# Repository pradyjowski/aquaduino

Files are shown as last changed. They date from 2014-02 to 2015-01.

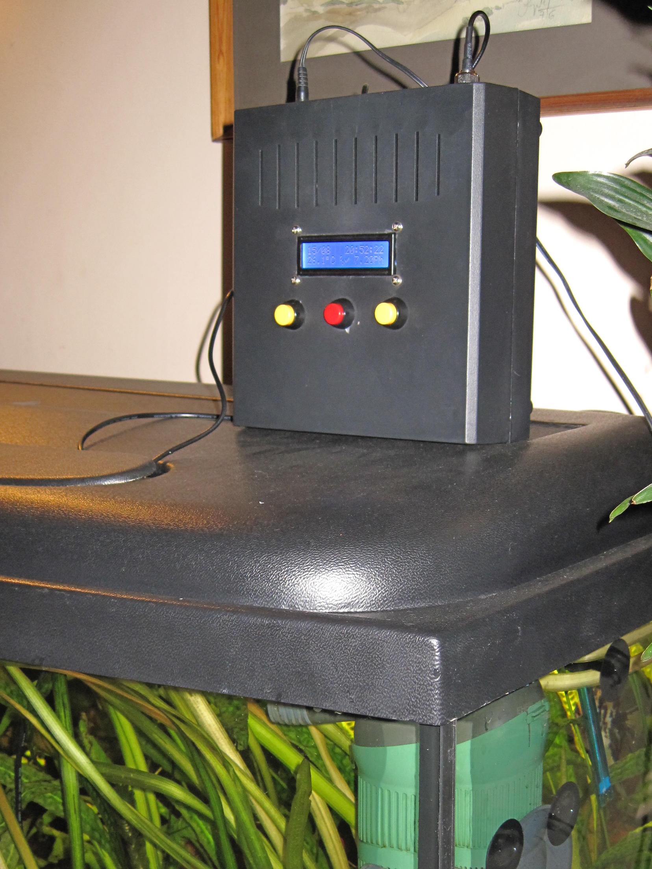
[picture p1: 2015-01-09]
IMG_3392.JPG

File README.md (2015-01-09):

aquaduino
=========

Arduino based aquarium controller measuring Ph and temperature, LCD-UI + RTC + datalogging SD

Achieved:
- LCD display over i2c interface
- Functional 3-button menu in English and Polish
- Ph probe reading with calibration code
- EEPROM save of Ph calibration
- Temperature reading [DS18B20]
- Data and clock [DS1307]
- SD card logging

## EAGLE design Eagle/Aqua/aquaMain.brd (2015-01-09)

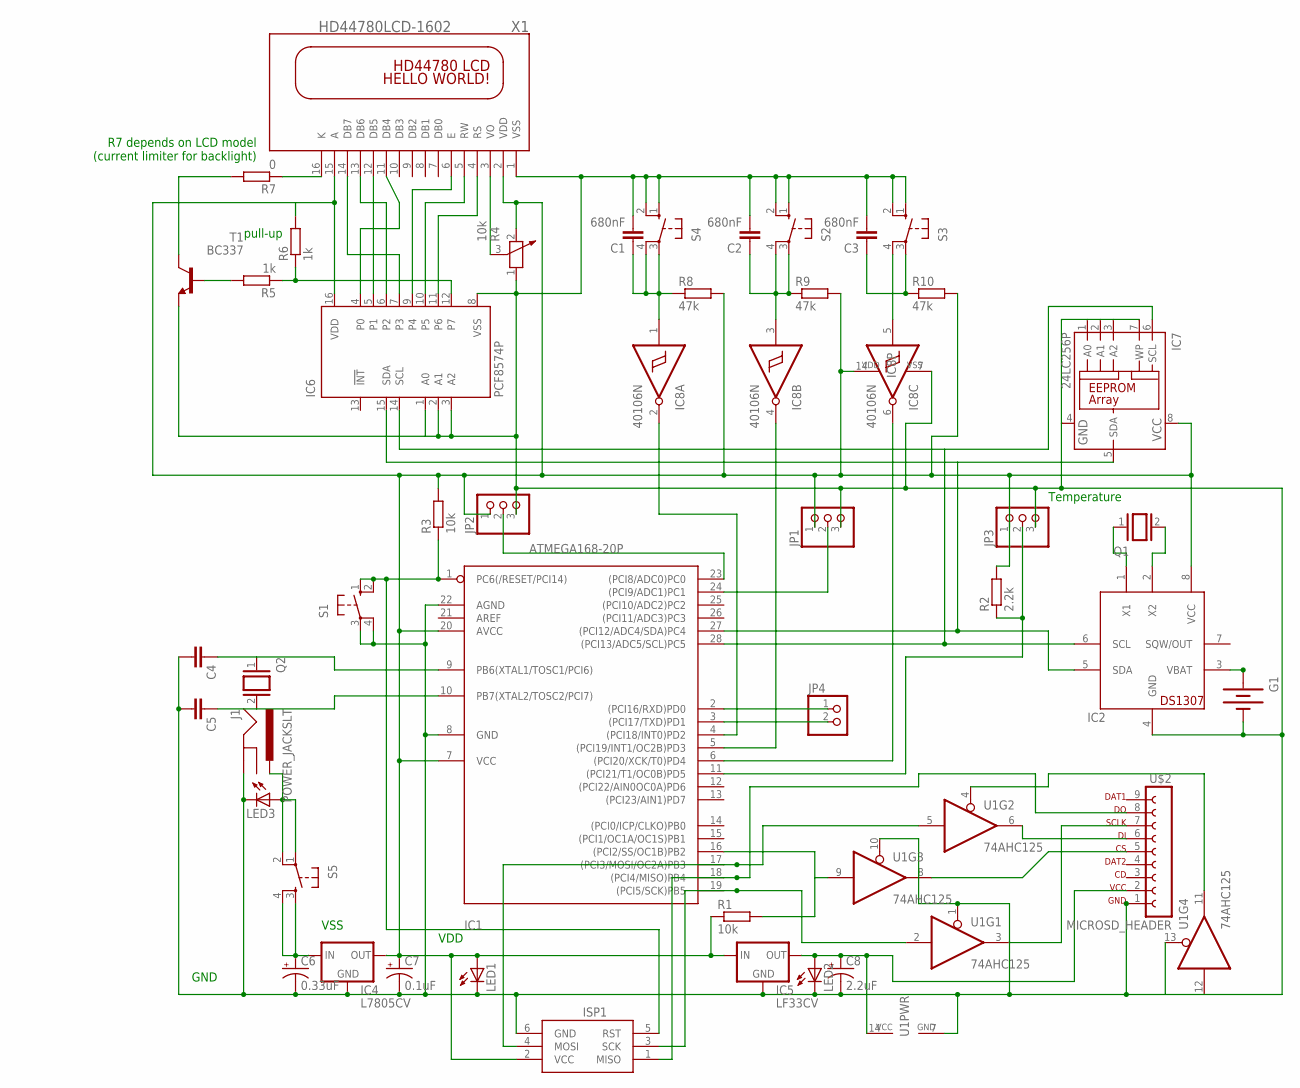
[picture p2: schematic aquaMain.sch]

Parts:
C1, C2, C3: 680nF; C050-050X075
C4, C5: C-EU025-024X044; C025-024X044
C6: 0.33uF; E5-6
C7: 0.1uF; E5-6
C8: 2.2uF; E5-6
G1: BATTERY20PTH; BATTCOM_20MM_PTH
IC1: ATMEGA168-20P; DIL28-3
IC2: DS1307; DIL08
IC4: L7805CV; TO220
IC5: LF33CV; TO220
IC6: PCF8574P; DIL16
IC7: 24LC256P; DIL8
IC8: 40106N; DIL14
ISP1: AVRISP-6; AVRISP
J1: POWER_JACKSLT; POWER_JACK_SLOT
JP1, JP2, JP3: PINHD-1X3; 1X03
JP4: PINHD-1X2; 1X02
LED1, LED2, LED3: LED3MM
Q1, Q2: XTAL/S; QS
R1, R3: 10k; 0204/7
R2: 2.2k; 0204/7
R4: 10k; PT-10
R5, R6: 1k; 0204/5
R7: 0; 0204/5
R8, R9, R10: 47k; 0204/5
S1, S2, S3, S4: 40-XX-ROUND; B3F-40XX-ROUND
S5: TAC_SWITCHPTH; TACTILE-PTH
T1: BC337; TO92
U1: 74AHC125; DIP14
U$2: MICROSD_HEADER; 9PINH
X1: HD44780LCD-1602; LCD1602

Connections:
unnamed: IC1.23 ((PCI8/ADC0)PC0), JP2.2
unnamed: IC1.5 ((PCI19/INT1/OC2B)PD3), IC8.4 (O)
unnamed: IC2.1 (X1), Q1.1
unnamed: IC2.2 (X2), Q1.2
unnamed: G1.1 (+), IC2.3 (VBAT)
unnamed: IC1.11 ((PCI21/T1/OC0B)PD5), JP3.2, R2.1
unnamed: IC1.28 ((PCI13/ADC5/SCL)PC5), IC2.6 (SCL), IC6.14 (SCL), IC7.6 (SCL)
unnamed: IC1.4 ((PCI18/INT0)PD2), IC8.2 (O)
unnamed: IC1.6 ((PCI20/XCK/T0)PD4), IC8.6 (O)
unnamed: C4.1, IC1.9 (PB6(XTAL1/TOSC1/PCI6)), Q2.1
unnamed: C5.1, IC1.10 (PB7(XTAL2/TOSC2/PCI7)), Q2.2
unnamed: IC1.18 ((PCI4/MISO)PB4), ISP1.1 (MISO), U$2.8
unnamed: IC1.17 ((PCI3/MOSI/OC2A)PB3), ISP1.4 (MOSI), U1.5 (I)
unnamed: IC1.16 ((PCI2/SS/OC1B)PB2), R1.2, U1.9 (I)
unnamed: IC1.19 ((PCI5/SCK)PB5), ISP1.3 (SCK), U1.2 (I)
unnamed: U1.3 (O), U$2.7
unnamed: U1.8 (O), U$2.5
unnamed: U1.6 (O), U$2.6
unnamed: IC1.1 (PC6(/RESET/PCI14)), ISP1.5 (RST), R3.1, S1.1 (S), S1.2 (S1)
unnamed: IC1.27 ((PCI12/ADC4/SDA)PC4), IC2.5 (SDA), IC6.15 (SDA), IC7.5 (SDA)
unnamed: C8.+, IC5.VOUT (OUT), LED2.A, U1.14 (VCC), U$2.2
unnamed: R4.3, X1.3 (VO)
unnamed: IC1.24 ((PCI9/ADC1)PC1), JP1.2
unnamed: C7.+, IC1.7 (VCC), IC1.20 (AVCC), IC2.8 (VCC), IC4.VOUT (OUT), IC5.VIN (IN), IC6.16 (VDD), IC7.8 (VCC), IC8.14 (VDD), ISP1.2 (VCC), JP1.1, JP2.1, JP3.1, LED1.A, R1.1, R2.2, R3.2, R4.2, R6.2, R8.2, R9.2, R10.2, X1.2 (VDD), X1.15 (A)
unnamed: J1.PWR, LED3.A, S5.1, S5.2
unnamed: IC6.4 (P0), X1.11 (DB4)
unnamed: IC6.5 (P1), X1.12 (DB5)
unnamed: IC6.6 (P2), X1.13 (DB6)
unnamed: IC6.7 (P3), X1.14 (DB7)
unnamed: IC6.9 (P4), X1.6 (E)
unnamed: IC6.10 (P5), X1.5 (RW)
unnamed: IC6.11 (P6), X1.4 (RS)
unnamed: IC6.12 (P7), R5.1, R6.1
unnamed: R5.2, T1.2 (B)
unnamed: R7.1, X1.16 (K)
unnamed: R7.2, T1.3 (C)
unnamed: C1.1, IC8.1 (I), R8.1, S4.3, S4.4 (P1)
unnamed: C2.1, IC8.3 (I), R9.1, S2.3, S2.4 (P1)
unnamed: C3.1, IC8.5 (I), R10.1, S3.3, S3.4 (P1)
unnamed: C6.+, IC4.VIN (IN), S5.3, S5.4
unnamed: IC1.2 ((PCI16/RXD)PD0), JP4.1
unnamed: IC1.3 ((PCI17/TXD)PD1), JP4.2
unnamed: U1.4 (OE), U1.11 (O)
VSS: C1.2, C2.2, C3.2, C4.2, C5.2, C6.-, C7.-, C8.-, G1.2 (-), IC1.8 (GND), IC1.22 (AGND), IC2.4 (GND), IC4.GND, IC5.GND, IC6.1 (A0), IC6.2 (A1), IC6.3 (A2), IC6.8 (VSS), IC7.1 (A0), IC7.2 (A1), IC7.3 (A2), IC7.4 (GND), IC7.7 (WP), IC8.7 (VSS), ISP1.6 (GND), J1.GND@2 (GND), JP1.3, JP2.3, JP3.3, LED1.K (C), LED2.K (C), LED3.K (C), R4.1, S1.3, S1.4 (P1), S2.1 (S), S2.2 (S1), S3.1 (S), S3.2 (S1), S4.1 (S), S4.2 (S1), T1.1 (E), U1.1 (OE), U1.7 (GND), U1.10 (OE), U1.12 (I), U1.13 (OE), U$2.1, X1.1 (VSS)

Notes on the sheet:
Temperature
R7 depends on LCD model (current limiter for backlight)
pull-up
GND
VSS
VDD

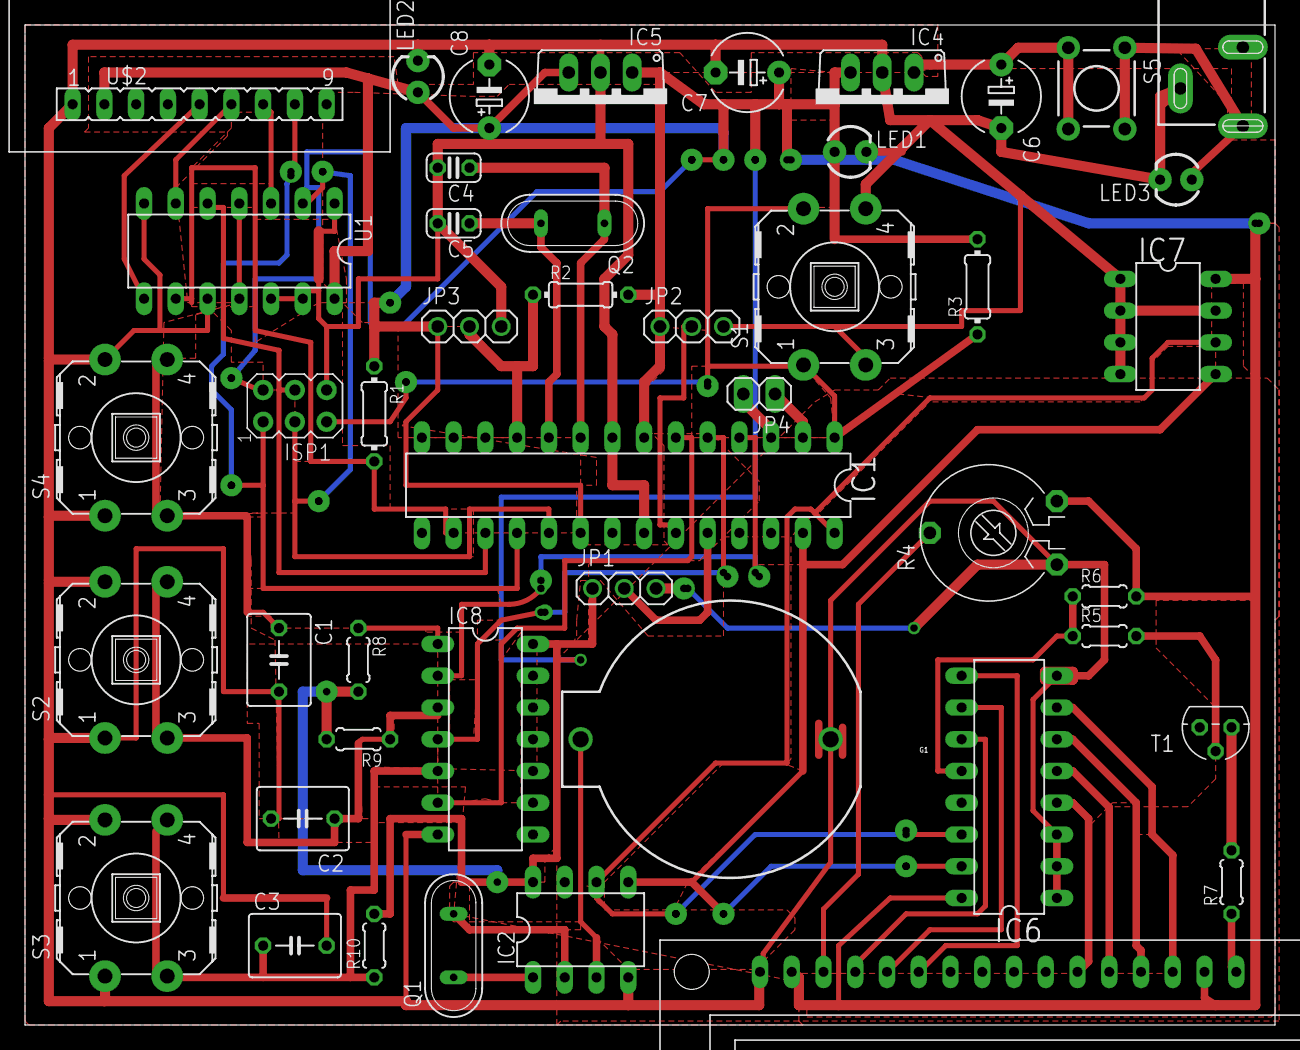
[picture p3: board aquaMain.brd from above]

Board: 2 copper layers, 100.0 x 80.0 mm, 46 parts (0 on the bottom side), 44 nets.

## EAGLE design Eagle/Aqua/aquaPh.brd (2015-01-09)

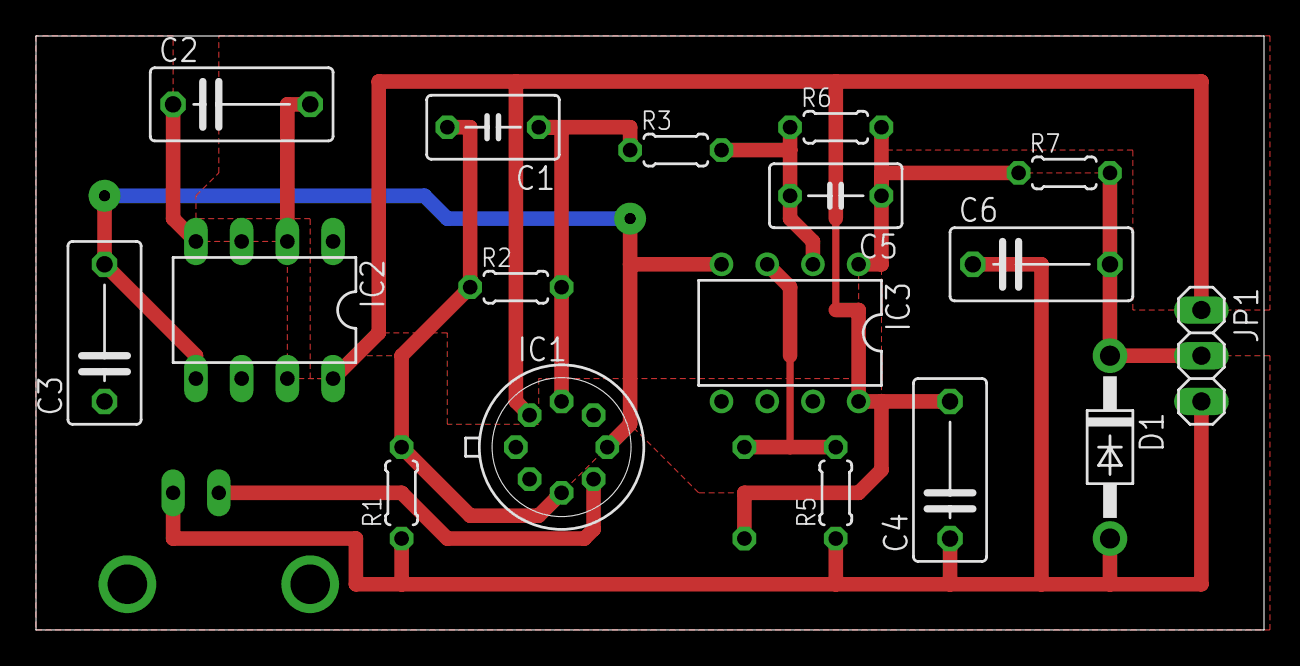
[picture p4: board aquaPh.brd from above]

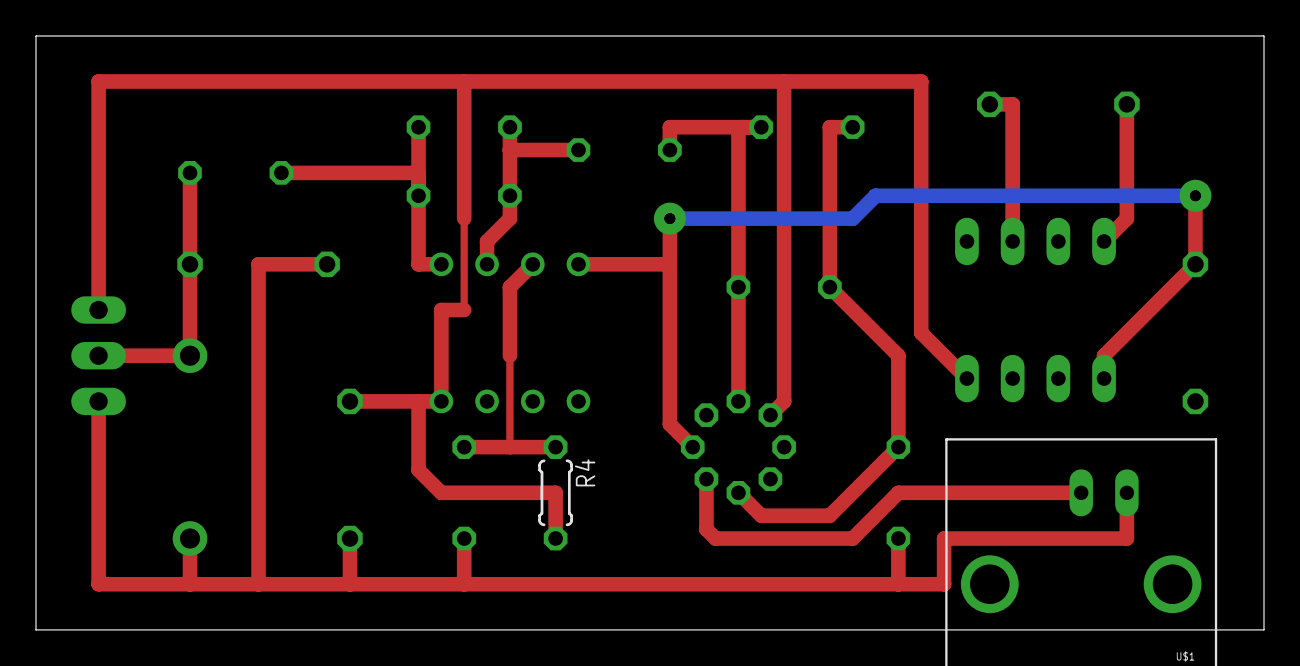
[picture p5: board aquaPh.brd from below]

Board: 2 copper layers, 68.2 x 33.0 mm, 19 parts (2 on the bottom side), 12 nets.

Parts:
C1, C5: 1uF; C050-035X075
C2, C3, C6: 10uF; C075-042X103
C4: 470uF; C075-042X103
D1: 1N4004; DO41-10
IC1: CA3140T; TO99
IC2: ICL7660CPA; DIL08
IC3: TL072P; DIL08
JP1: 1X03
R1, R4: 33k; 0204/5
R2: 200k; 0204/5
R3, R5: 10k; 0204/5
R6: 12k; 0204/5
R7: 4.7k; 0204/5
U$1: BNCPTH; BNC

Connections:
-5V: C3.2, IC1.4, IC2.5, IC3.4
GND: C3.1, C4.1, C6.1, D1.A, IC2.3, JP1.3, R1.1, R5.1, U$1.GND
unnamed: IC1.3, U$1.S
unnamed: C1.2, IC1.2, R1.2, R2.1
unnamed: C2.1, IC2.4
unnamed: C2.2, IC2.2
unnamed: C1.1, IC1.6, R2.2, R3.1
unnamed: C5.2, IC3.2, R3.2, R6.1
unnamed: IC3.3, R4.1, R5.2
unnamed: C5.1, IC3.1, R6.2, R7.1
unnamed: C6.2, D1.C, JP1.2, R7.2
VCC: C4.2, IC1.7, IC2.8, IC3.8, JP1.1, R4.2

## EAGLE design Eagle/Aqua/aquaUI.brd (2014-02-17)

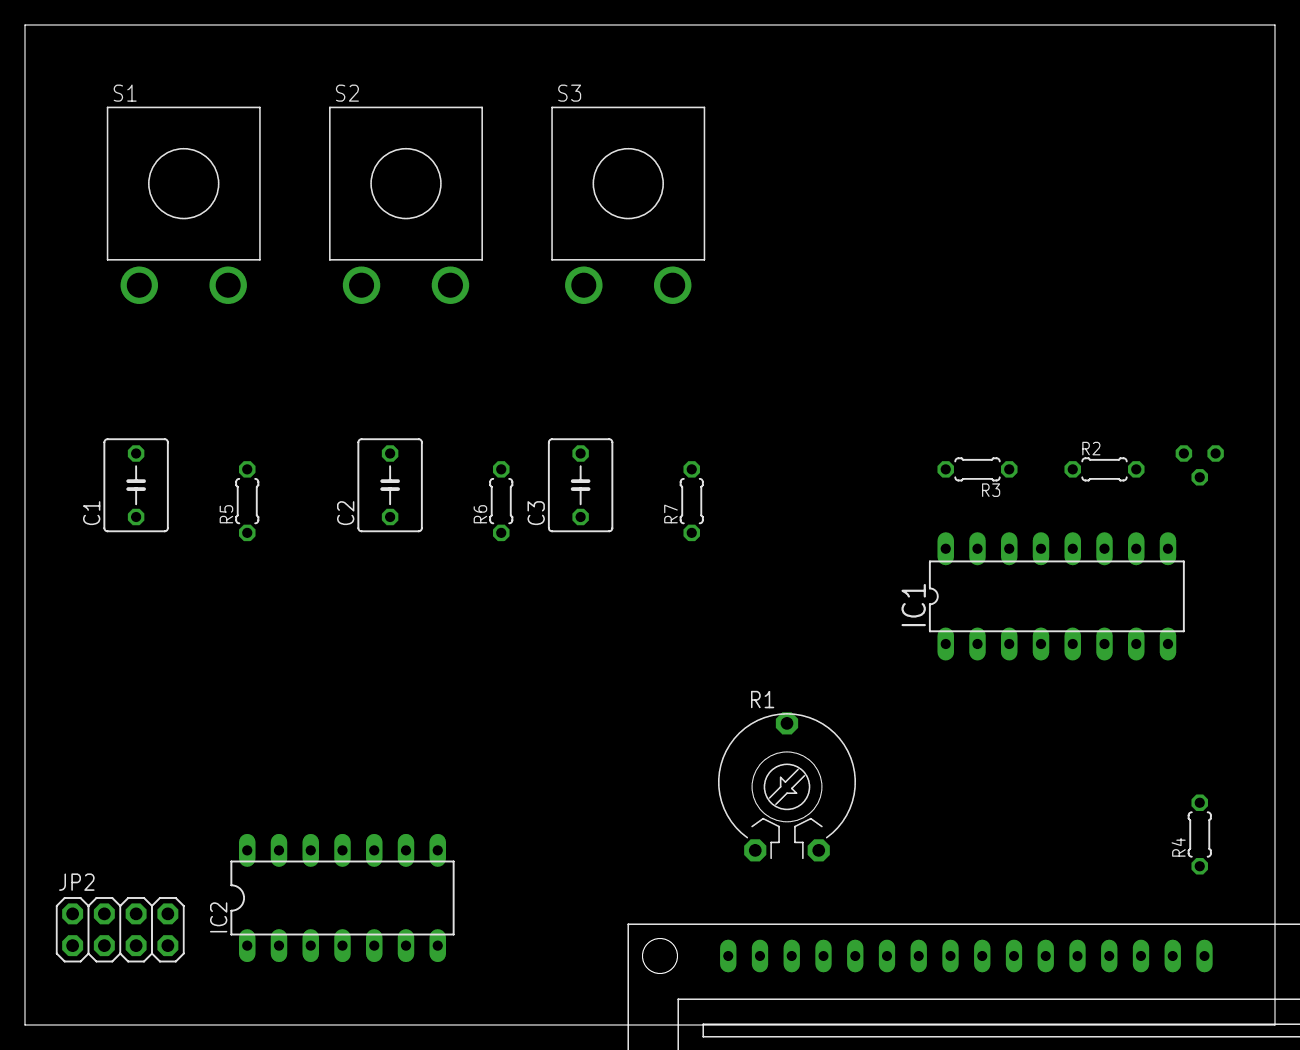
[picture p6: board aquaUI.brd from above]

Board: 2 copper layers, 100.0 x 80.0 mm, 18 parts (1 on the bottom side), 22 nets, no tracks yet.

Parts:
C1, C2, C3: 680nF; C050-050X075
IC1: PCF8574P; DIL16
IC2: 40106N; DIL14
JP2: 2X04
R1: 10k; PT-10
R2, R3: 1k; 0204/5
R4: 0; 0204/5
R5, R6, R7: 47k; 0204/5
S1, S2, S3: SPST; JUDCOSPST
T1: BC337; TO92
X1: HD44780LCD-1602; LCD1602

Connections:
+5V: IC1.16, IC2.14, JP2.1, R1.1, R3.2, R5.2, R6.2, R7.2, X1.2, X1.15
GND: C1.2, C2.2, C3.2, IC1.1, IC1.2, IC1.3, IC1.8, IC2.7, JP2.3, R1.2, S1.T, S2.T, S3.T, T1.3, X1.1
unnamed: IC1.15, JP2.2
unnamed: IC1.14, JP2.4
unnamed: R1.3, X1.3
unnamed: IC1.4, X1.11
unnamed: IC1.5, X1.12
unnamed: IC1.6, X1.13
unnamed: IC1.7, X1.14
unnamed: IC1.9, X1.6
unnamed: IC1.10, X1.5
unnamed: IC1.11, X1.4
unnamed: IC1.12, R2.1, R3.1
unnamed: R2.2, T1.2
unnamed: R4.1, X1.16
unnamed: R4.2, T1.1
unnamed: C1.1, IC2.1, R5.1, S1.P
unnamed: C2.1, IC2.3, R6.1, S2.P
unnamed: C3.1, IC2.5, R7.1, S3.P
unnamed: IC2.2, JP2.6
unnamed: IC2.6, JP2.5
unnamed: IC2.4, JP2.7

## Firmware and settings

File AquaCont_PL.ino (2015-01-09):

// include the library code
#include <EEPROM.h>             // save/read EEPROM
#include <Wire.h>               //i2c interface
#include <LiquidCrystal_I2C.h>  //lcd through pcf8574ap
#include <OneWire.h>            //onewire for temp
#include <DallasTemperature.h>  //temp sensor
#include "RTClib.h"             // RTC for DS1370
#include <SPI.h>                // SPI interface for SD card
#include <SdFat.h>              // SD card handler
#include <avr/pgmspace.h>       // saving in program memory

#define BTIME 100    //debouncing time for buttons
#define BYTE 8       //byte size
#define TOTALCUSTCHAR 5 // total amount of custom chars
#define TOTALPOS 8   //total menu options
#define TOTALSCR 3   //total screens
#define SENSORPIN A0 // Ph sensing pin
#define LTIME 30     //internal average logging time in seconds
#define MAXSTRLEN 16 // LCD row length

//various library-related variables
SdFat sd;
SdFile sdLog;
RTC_DS1307 rtc;
DateTime now;
LiquidCrystal_I2C lcd(0x38, 4, 5, 6, 0, 1, 2, 3, 7, POSITIVE); // addr, EN, RW, RS, D4, D5, D6, D7, BacklightPin, POLARITY
OneWire oneWire(5); // Setup a oneWire instance to communicate with any OneWire devices on Pin5
DallasTemperature sensors(&oneWire); // Pass our oneWire reference to Dallas Temperature. 
DeviceAddress T1 = { 0x28, 0x22, 0xAA, 0x68, 0x05, 0x00, 0x00, 0xF1 }; // Assign the addresses of your 1-Wire temp sensors.

// Menu options saved in program memory
static char buffer[MAXSTRLEN+1];
const char mi0[] PROGMEM = " Podswietlenie";
const char mi1[] PROGMEM = "  Logowanie SD";
const char mi2[] PROGMEM = "SD Czestotliwosc";
const char mi3[] PROGMEM = " Ph Kalibracja";
const char mi4[] PROGMEM = "Zapis Kalibracji";
const char mi5[] PROGMEM = "   Zmien Czas";
const char mi6[] PROGMEM = "   Zmien Date";
const char mi7[] PROGMEM = "     Wyjdz";

PGM_P const mi[] PROGMEM = 
{
    mi0,mi1,mi2,mi3,mi4,mi5,mi6,mi7
};

//Read calibration data from EEPROM
unsigned int phL=EEPROM.read(0)*256+EEPROM.read(1);
unsigned int phLv=EEPROM.read(4)*256+EEPROM.read(5);
unsigned int phH=EEPROM.read(2)*256+EEPROM.read(3);
unsigned int phHv=EEPROM.read(6)*256+EEPROM.read(7);

//Setup custom LCD characters
static const PROGMEM unsigned char signs[] = 
{     
   0x4,0xe,0x15,0x4,0x4,0x4,0x4,0x4,      //0 - arrow UP
   0x4,0x4,0x4,0x4,0x4,0x15,0xe,0x4,      //1 - arrow DOWN
   0x18,0x10,0x8,0x18,0x6,0x5,0x5,0x6,    //2 - SD sign 
   0x0,0x1,0x3,0x16,0x1c,0x8,0x0,0x0,     //3 - tick
   0x0,0x1b,0xe,0x4,0xe,0x1b,0x0,0x0,     //4 - cross      
}; 


volatile byte flag = 0;          // flag - screen id
volatile boolean clrscr = false; // flag - clear screen

boolean inMenu = false;     // flag - inside menu
byte menuPos = 0;           // position in menu

unsigned int avg_ph=0; unsigned int avg_temp=0; 
byte avg_count=0;           // total amount of logs summed in above
boolean SDlogging = true;   // flag - enable logging
boolean SDerror = false;    // flag - SD write error
byte logSDtime = 5;         // time [min] between SD save
char data[40];              // char buffer for main login line
char csPh[6];               // char buffer for logging ph
char csT[6];                // char buffer for logging temperature
uint32_t lastLog;           // used to time the logging

uint32_t lastButton;        //used for button debouncing in menu

void setup() {

  // Setup interrupts
  PCICR |= (1<<PCIE2);
  PCMSK2 |= (1<<PCINT20); //D4 -> 20
  MCUCR = (1<<ISC01) | (1<<ISC01);
  pinMode(2, INPUT);
  pinMode(3, INPUT);
  pinMode(4, INPUT);
  interrupts();
  
  // open interfaces
  Wire.begin();
  rtc.begin();
  sensors.begin();
  sensors.setResolution(T1, 12);// set the resolution to 12 bit
  sensors.requestTemperatures();
  lcd.begin(16,2);
  lcd.setBacklight(BACKLIGHT_ON);
  
  //load extra signs into LCD memory
  unsigned char buf[BYTE];
  for (unsigned char i=0; i<TOTALCUSTCHAR; i++) {
    for(unsigned char j=0; j<BYTE; j++) 
       { 
           buf[j]=pgm_read_byte_near(&signs[j+BYTE*i]); 
       }
    lcd.createChar(i, buf);
  }
  
  // set compile time if RTC not working
  if (! rtc.isrunning()) {
    //  Serial.println("RTC is NOT running!");
    //  following line sets the RTC to the date & time this sketch was compiled
    rtc.adjust(DateTime(__DATE__, __TIME__));
  }
  
  // get time
  lcd.clear();
  now = rtc.now();
  lastLog=now.unixtime();
  
  // initialize SD card
  lcd.print(F("Start SD"));
  delay(500);
  // Initialize SdFat
  if (!sd.begin(10, SPI_QUARTER_SPEED)) {
    lcd.print(F(" - blad"));
    lcd.setCursor(1,0);
    sd.initErrorPrint();
    SDerror=true;
    delay(5000);
  } else {
    now = rtc.now();
    char fname[14];
    sprintf(fname,  "log_%d_%d.csv", now.month(), now.day());
    // if initialized correctly open the file for write at end like the Native SD library
    if (!sdLog.open(fname, O_RDWR | O_CREAT | O_AT_END)) {
      lcd.setCursor(0, 0);
      lcd.print(F("SD blad pliku"));
      lcd.setCursor(1,0); SDerror=true;
      sd.initErrorPrint();
      delay(5000);
    } else {
      lcd.print(F(" OK"));
      delay(2000);
    }
  }

}


void loop() {
  // check for clearing screen
  if (clrscr) {
    lcd.clear();
    clrscr=false;
  }
  // get time
  now = rtc.now();
  if ( lastLog + LTIME < now.unixtime() ) //check if time to log
    {
    if (SDlogging) logData();
    lastLog = now.unixtime();
    } 
  else  // otherwise show screen
   {
   switch (flag) {
    case 0:
      showTimeScreen();
      break;
    case 2:
      showRAW();
      break;
    case 1:
      showMenu();
      break;
    default:
      flag=0;
      break;
   }
  }

}

// interrupt function - change screen no if NOT in menu
ISR(PCINT2_vect)
{
  if( digitalRead(4) == 1 && !inMenu) {
    flag++;
    flag=flag % TOTALSCR;
    clrscr=true;
  }
}

// show main screen
void showTimeScreen()
{
  //update time
  sprintf(data,  "%02d/%02d   %02d:%02d:%02d", now.day(), now.month(), now.hour(), now.minute(), now.second() );
  lcd.setCursor(0, 0);
  lcd.print(data);
  //update temp
  lcd.setCursor(0, 1);
  lcd.print(sensors.getTempC(T1),1);
  lcd.write((uint8_t)223);
  lcd.print("C");
  sensors.requestTemperatures(); // ask for new one
  //update Ph
  lcd.setCursor(10, 1);
  lcd.print(0.01*mapfloat(analogRead(SENSORPIN),phL,phH,phLv,phHv),2);
  lcd.print("Ph");
  //update SD status
  lcd.setCursor(7,1);
  lcd.write((uint8_t)2);
  if (SDerror) lcd.print("!");
  else if (SDlogging)  lcd.write((uint8_t)3);
       else lcd.write((uint8_t)4);
}

// show simple screen for debug & calibration
void showRAW() { 
    lcd.setCursor(0, 0);          
    lcd.print(F("Temp:  "));
    lcd.print(sensors.getTempC(T1),2);
    lcd.print(" ");
    lcd.write((uint8_t)223);
    lcd.print("C");
    lcd.setCursor(0, 1);
    lcd.print(F("Ph  :  "));
    lcd.print(analogRead(SENSORPIN));
    sensors.requestTemperatures();
    delay(BTIME);
  }

// data logging
void logData() { 
  lcd.setCursor(5,0);
  lcd.print("*"); // heart-beat
  delay(100);
  // sum to a variable-container
  if (avg_count <= 255) { //prevent overflows
    avg_ph += analogRead(SENSORPIN); 
    avg_temp += (int) 100*sensors.getTempC(T1);
    avg_count++;
  }
  //if time to log on SD
  if (avg_count*LTIME/60 >= logSDtime) { 
    dtostrf(0.01*mapfloat((float) avg_ph/avg_count,phL,phH,phLv,phHv),1,2,csPh); // convert float Ph into char table
    dtostrf((float) 0.01*avg_temp/avg_count,1,2,csT);                            // convert float Temp into char table
    DateTime logt (now.unixtime() - 0.5*avg_count*LTIME);                        // save mid-time between SD logs
    //create saving buffer
    sprintf(data,  "%d,%d,%d,%d,%d,%d,%s,%s", logt.year(), logt.month(), logt.day(), logt.hour(), logt.minute(), logt.second(), csT, csPh );
    saveSD(); // save on SD
    avg_ph=0; avg_temp=0; avg_count=0; //reset counters
  }
  lcd.setCursor(5,0);
  lcd.print(" "); // remove heart-beat
}

// save prepared buffer "data" on SD card
void saveSD() {
  lcd.clear();
  lcd.setCursor(0, 0);  
  lcd.print(F("SD Zapis..."));
  lcd.setCursor(3,1); // show saved values, why not
  lcd.print(csT); lcd.print(F(" ")); lcd.print(csPh);
  delay(1000);
  sdLog.println(data);  // SAVE
  lcd.setCursor(8,0);
  //command to sync the SD card
  if (!sdLog.sync()) { //if failed
    
    lcd.print(F(" blad"));
    sd.errorPrint(); SDerror=true;
  } else { // success
    lcd.print(F(" OK"));
  };
  delay(1000);
  lcd.clear();
}  

// liner mapping for float values
float mapfloat(long x, long in_min, long in_max, int out_min, long out_max) {
  return (float)(x - in_min) * (out_max - out_min) / (float)(in_max - in_min) + out_min;
}

// read buttons in menu
byte readButton() {
  byte button = 0;
  
  if ( lastButton + BTIME < millis() ) {
    //UP
    if (digitalRead(2)) { button=button+1; lastButton=millis(); }
    //DOWN
    if (digitalRead(3)) { button=button+2; lastButton=millis(); } 
    //SELECT
    if (digitalRead(4)) { button=button+4; lastButton=millis(); }   
  }
  return button; 
}

// shows up/down arrows at the edges of the screen
void showArrows() {
  lcd.setCursor(0,1); lcd.write((uint8_t)0); lcd.setCursor(15,1); lcd.write((uint8_t)1);
}

// shows Yes/No options at the edges of the screen
void showYESNO(){
  lcd.setCursor(0,1); lcd.print(F("TAK          NIE"));
}

// shows current menu option (title) from progmem
void menuLine(byte menuPos) {
  char lcdbuffer[MAXSTRLEN+1];
  lcd.clear();
  strcpy_P(lcdbuffer, (char*)pgm_read_word(&(mi[menuPos])));        
  lcd.print(lcdbuffer);
  showArrows();
  lcd.setCursor(7,1); lcd.print("OK");
}  

// represents int as 1/100th float
void showFloat(int number) {
  lcd.setCursor(6,1); lcd.print((int) number / 100 ); lcd.print("."); if (number % 100 < 10) lcd.print("0"); lcd.print(number % 100);
}

// show MENU screen
void showMenu() {
  lcd.setCursor(5, 0);
  lcd.print(F("MENU"));
  showArrows();
  lcd.setCursor(5,1); lcd.print(F("Wejdz"));
  delay(BTIME);
  byte a=readButton();
  if (a == 1 || a == 2) { // if Up or Down pressed - ented menu
    //prepare variables
    byte b=0; byte c=0; byte d=0; char temp[BYTE]; boolean flicker=true;
    inMenu=true; menuPos=0; // set flag
    menuLine(menuPos); // draw menu positon
    do {     
      delay(300); //debounce
      switch (readButton()) {
        case 1: // UP button
        menuPos++;
        menuPos=menuPos % TOTALPOS;
        menuLine(menuPos);
        break;
        case 2: // DOWN button   
        menuPos--;
        menuPos=menuPos % TOTALPOS;
        menuLine(menuPos);
        break;
        
        case 4: //OK button
        switch (menuPos){
          
          case 0:  //BACKLIGHT MENU
          showYESNO();
          delay(1000); a=0;
          while (a == 0) {delay(BTIME); a=readButton();}
          if (a == 1) {lcd.setBacklight(BACKLIGHT_ON);} 
          else if (a == 2) {lcd.setBacklight(BACKLIGHT_OFF);};     
          delay(500);
          menuLine(menuPos);        
          break;
          
          case 1:  //SD LOG FLAG MENU
          showYESNO();
          delay(1000); a=0;
          while (a == 0) {delay(BTIME); a=readButton();}
          if (a == 1) {SDlogging = true; avg_ph=0; avg_temp=0; avg_count=0; now = rtc.now(); lastLog = now.unixtime();}
          else if (a == 2) SDlogging = false;     
          delay(500);
          menuLine(menuPos);
          break;
         
          case 2: //SD SYNC FREQUENCY MENU
          lcd.clear();
          lcd.print(F("Ustaw czest. SD"));
          showArrows();
          lcd.setCursor(5,1); 
          if (logSDtime<10) lcd.print("0");
          lcd.print(logSDtime); lcd.print(F(" min")); 
          a=0; delay(1000);
          do {
            delay(BTIME); 
            if (a==1) logSDtime++;
            if (a==2) logSDtime--;
            logSDtime = logSDtime % 128; //max 127mins between SD sync
            lcd.setCursor(5,1);
            if (logSDtime < 10) lcd.print("0");
            lcd.print(logSDtime);
            a=readButton();
          } while (a!=4);  // OK to finish
          delay(500);
          menuLine(menuPos);
          break;
          
          case 3: // PH CALIBRATION
          lcd.clear();
          lcd.print(F("Niski Ph"));
          showArrows();
          showFloat(phLv);
          a=0; delay(1000);
          do {
            delay(BTIME); 
            if (a==1) phLv++;
            if (a==2) phLv--;
            showFloat(phLv);
            a=readButton();
          } while (a!=4) ; // OK to next
          
          lcd.clear();
          lcd.print(F("Niski Ph Odczyt"));
          showArrows();
          lcd.setCursor(6,1); lcd.print(phL);
          a=0; delay(1000);
          do {
            delay(BTIME); 
            if (a==1) phL++;
            if (a==2) phL--;
            if (phL < 100) lcd.setCursor(6,1); lcd.print(F("    "));
            lcd.setCursor(6,1); lcd.print(phL);
            a=readButton();
          } while (a!=4); // OK to next         
          
          lcd.clear();
          lcd.print(F("Wysoki Ph"));
          showArrows();
          showFloat(phHv);
          a=0; delay(1000);
          do {
            delay(BTIME); 
            if (a==1) phHv++;
            if (a==2) phHv--;
            showFloat(phHv);
            a=readButton();
          } while (a!=4) ;
          
          lcd.clear();
          lcd.print(F("Wysoki Ph Odczyt"));
          showArrows();
          lcd.setCursor(6,1); lcd.print(phH);
          a=0; delay(1000);
          do {
            delay(BTIME); 
            if (a==1) phH++;
            if (a==2) phH--;
            if (phL < 100) lcd.setCursor(6,1); lcd.print(F("    "));
            lcd.setCursor(6,1); lcd.print(phH);
            a=readButton();
          } while (a!=4);
          delay(500);
          menuLine(menuPos);
          break;
          
          case 4: //SAVE ON EEPROM 
          showYESNO();
          delay(3000); a=0;
          lcd.setCursor(5,1); lcd.print(F("Wybierz"));
          while (a == 0) {delay(BTIME); a=readButton();}
          if (a == 1) {
            a=0; b=0;
            // lower PH value
            a = phL & 0xff; b = (phL >> BYTE);
            EEPROM.write(0,b); EEPROM.write(1,a);
            // higher PH value
            a = phH & 0xff; b = (phH >> BYTE);
            EEPROM.write(2,b); EEPROM.write(3,a);
            // lower PH reading
            a = phLv & 0xff; b = (phLv >> BYTE);
            EEPROM.write(4,b); EEPROM.write(5,a);
            // higher PH reading
            a = phHv & 0xff; b = (phHv >> BYTE);
            EEPROM.write(6,b); EEPROM.write(7,a);
            lcd.setCursor(0,1); lcd.print(F("    Zapisane    "));  
          }
          else if (a == 2) lcd.setCursor(0,1); lcd.print(F("  Nie Zapisane  "));     
          delay(2000);
          menuLine(menuPos);
          break;
          
          case 5: //SET TIME
          lcd.clear();
          now = rtc.now();
          d = now.second();
          c = now.minute();
          b = now.hour();
          sprintf(temp,  "%02d:%02d:%02d", b,c,d );
          showArrows();
          lcd.setCursor(4, 1); lcd.print(temp);
          a=0; delay(1000);          
          do { // HOURS
            delay(200); 
            if (a==1) b++;
            if (a==2) b--;
            b=b % 24;
            if (flicker) sprintf(temp,  "  :%02d:%02d", c,d );
            else sprintf(temp,  "%02d:%02d:%02d", b,c,d );
            flicker=!flicker;
            lcd.setCursor(4, 1); lcd.print(temp);
            a=readButton();
          } while (a!=4);
          delay(1000);
          do { //MINS
            delay(200); 
            if (a==1) c++;
            if (a==2) c--;
            c= c % 60;
            if (flicker) sprintf(temp,  "%02d:  :%02d", b,d );
            else sprintf(temp,  "%02d:%02d:%02d", b,c,d );
            flicker=!flicker;
            lcd.setCursor(4, 1); lcd.print(temp);
            a=readButton();
          } while (a!=4);
          delay(1000);
          do { //SECONDS
            delay(200); 
            if (a==1) d++;
            if (a==2) d--;
            d= d % 60;
            if (flicker) sprintf(temp,  "%02d:%02d:  ", b,c );
            else sprintf(temp,  "%02d:%02d:%02d", b,c,d );
            flicker=!flicker;
            sprintf(temp,  "%02d:%02d:%02d", b,c,d );
            lcd.setCursor(4, 1); lcd.print(temp);
            a=readButton();
          } while (a!=4);
          showYESNO();
          lcd.setCursor(4, 0); lcd.print(temp);
          lcd.setCursor(5,1);
          lcd.print(F("Zapis?"));
          delay(500); a=0;
          while (a == 0 || a == 4) {delay(BTIME); a=readButton();}
          if (a == 1) { SDlogging = false; now = rtc.now();
            rtc.adjust(DateTime(now.year(),now.month(),now.day(), (uint8_t) b, (uint8_t) c, (uint8_t) d));
            lcd.setCursor(0,1); lcd.print(F("    Zapisane    "));
          } else lcd.setCursor(0,1); lcd.print(F("  Nie Zapisane  "));
          delay(2000);
          menuLine(menuPos);
          break;
          
          case 6: //SET DATE
          lcd.clear();
          now = rtc.now();
          b = now.day();
          c = now.month();
          d = now.year() % 2000;
          sprintf(temp,  "%02d/%02d/%02d", b,c,d );
          showArrows();
          lcd.setCursor(4, 1); lcd.print(temp);
          a=0; delay(1000);          
          do { // DAYS
            delay(200); 
            if (a==1) b++;
            if (a==2) b--;
            b = b % 32;
            if (flicker) sprintf(temp,  "  /%02d/%02d", c,d );
            else sprintf(temp,  "%02d/%02d/%02d", b,c,d );
            flicker=!flicker;
            lcd.setCursor(4, 1); lcd.print(temp);
            a=readButton();
          } while (a!=4);
          delay(1000);
          do { //MONTHS
            delay(200); 
            if (a==1) c++;
            if (a==2) c--;
            c= c % 13;
            if (c == 0) c++;
            if (flicker) sprintf(temp,  "%02d/  /%02d", b,d );
            else sprintf(temp,  "%02d/%02d/%02d", b,c,d );
            flicker=!flicker;
            lcd.setCursor(4, 1); lcd.print(temp);
            a=readButton();
          } while (a!=4);
          delay(1000);
          do { //YEARS
            delay(200); 
            if (a==1) d++;
            if (a==2) d--;
            d= d % 100;
            if (flicker) sprintf(temp,  "%02d/%02d/  ", b,c );
            else sprintf(temp,  "%02d/%02d/%02d", b,c,d );
            flicker=!flicker;
            lcd.setCursor(4, 1); lcd.print(temp);
            a=readButton();
          } while (a!=4);
          showYESNO();
          sprintf(temp,  "%02d/%02d/%02d", b,c,d );
          lcd.setCursor(4, 0); lcd.print(temp);
          lcd.setCursor(5,1);
          lcd.print(F("Zapis?"));
          delay(500); a=0;
          while (a == 0 || a == 4) {delay(BTIME); a=readButton();}
          if (a == 1) { SDlogging = false; now = rtc.now();
            rtc.adjust(DateTime((uint8_t) d+2000, (uint8_t) c, (uint8_t) b, now.hour(),now.minute(),now.second()));
            lcd.setCursor(0,1); lcd.print(F("    Zapisane    "));
          } else lcd.setCursor(0,1); lcd.print(F("  Nie Zapisane  "));
          delay(2000);
          menuLine(menuPos);
          break;
          
          case 7: //EXIT MENU
          lcd.clear();
          lcd.setCursor(0,0);
          menuLine(menuPos); 
          showYESNO();
          lcd.setCursor(5,1);
          lcd.print(F("Wyjdz?"));
          delay(1000); a=0;
          while (a == 0 || a == 4) {delay(BTIME); a=readButton();}
          if (a == 1) {inMenu = false; flag=0; clrscr=true;}
          else menuLine(menuPos);
          delay(500);
          break;
        }
        
        break; // break menu screen ( 4 - UP )
        
        default:
        break;
      }
    } while (inMenu); // loop menu case until Exit menu selected
  }
}

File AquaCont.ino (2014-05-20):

// include the library code
#include <EEPROM.h>
#include <Wire.h>   //i2c interface
#include <LiquidCrystal_I2C.h> //lcd through pcf8574ap
#include <OneWire.h> //onewire for temp
#include <DallasTemperature.h> //temp sensor
#include "RTClib.h"
#include <SPI.h>
#include <SdFat.h>
#include <avr/io.h>
#include <avr/interrupt.h>


SdFat sd;
SdFile sdLog;
char data[40];
char csPh[6];
char csT[6];

LiquidCrystal_I2C lcd(0x38, 4, 5, 6, 0, 1, 2, 3, 7, POSITIVE); // addr, EN, RW, RS, D4, D5, D6, D7, BacklightPin, POLARITY

RTC_DS1307 rtc;

OneWire oneWire(5); // Setup a oneWire instance to communicate with any OneWire devices on Pin5
DallasTemperature sensors(&oneWire); // Pass our oneWire reference to Dallas Temperature. 
DeviceAddress T1 = { 0x28, 0x22, 0xAA, 0x68, 0x05, 0x00, 0x00, 0xF1 }; // Assign the addresses of your 1-Wire temp sensors.

volatile byte flag = 0;
volatile byte seconds = 0;
byte flag_last=0;
volatile boolean light = true;
boolean light_last = true;
boolean logging = true;


int sensorPin = A0;

/*unsigned int phL = 120;
byte phLlow = phL & 0xff;
byte phLhigh = (phL >> 8);
unsigned int phH = 600;
byte phHlow = phH & 0xff;
byte phHhigh = (phH >> 8);*/
/*
int phL=EEPROM.read(0)*256+EEPROM.read(1);
int phLv=EEPROM.read(4)*256+EEPROM.read(5);
int phH=EEPROM.read(2)*256+EEPROM.read(3);
int phHv=EEPROM.read(6)*256+EEPROM.read(7);
*/
//temporary until EEPROM fixed
int phL=120; int phLv=400; int phH=600; int phHv=700;



void setup() {
  Wire.begin();
  rtc.begin();
  sensors.begin();
  sensors.setResolution(T1, 12);// set the resolution to 10 bit (good enough?)
  Serial.begin(19200);
  lcd.begin(16,2);
  lcd.setBacklight(BACKLIGHT_ON);

  pinMode(2, INPUT);
  pinMode(3, INPUT);
  pinMode(4, INPUT);
 
  if (! rtc.isrunning()) {
    //  Serial.println("RTC is NOT running!");
    //  following line sets the RTC to the date & time this sketch was compiled
    rtc.adjust(DateTime(__DATE__, __TIME__));
  }
  
  lcd.clear();
  
  // initialize Timer1
  cli();          // disable global interrupts
  
  EICRA |= (1 << ISC01);    // set INT0 to trigger on failing edge
  EIMSK |= (1 << INT0);     // Turns on INT0
  
  TCCR1A = 0;     // set entire TCCR1A register to 0
  TCCR1B = 0;     // same for TCCR1B
 
  // set compare match register to desired timer count:
  // 1s@16MHz/1024 = 15624 
  // 4s@16MHz/1024 = 62496
  OCR1A = 62496;
  // turn on CTC mode:
  TCCR1B |= (1 << WGM12);
  // Set CS10 and CS12 bits for 1024 prescaler:
  TCCR1B |= (1 << CS10);
  TCCR1B |= (1 << CS12);
  // enable timer compare interrupt:
  TIMSK1 |= (1 << OCIE1A);
  // enable global interrupts:

  sei();
   
  //attachInterrupt(0, swap, RISING);
  lcd.clear();
  lcd.print("INIT SD");
  delay(500);
  // Initialize SdFat
  if (!sd.begin(10, SPI_QUARTER_SPEED)) {
    lcd.print(" - error");
    lcd.setCursor(1,0);
    sd.initErrorPrint();
    delay(5000);
  } else {
    // if initialized correctly open the file for write at end like the Native SD library
    if (!sdLog.open("datalog.txt", O_RDWR | O_CREAT | O_AT_END)) {
      lcd.setCursor(0, 0);
      lcd.print("SD write error  ");
      lcd.setCursor(1,0);
      sd.initErrorPrint();
      delay(5000);
    } else {
      lcd.print(" OK");
      delay(2000);
    }
  }
}

void loop() {
  //Serial.println(flag);
  
  switch (flag) {
    case 0:
      showTimeScreen();
      break;
    case 1:
      showReadingsScreen();
//      calibrate();
//      saveOnEEPROM();
      break;
    case 2:
      showMenu();
//      swap();
      break;
    case 10:
//      showSD();
//      logDataShow();
      if (logging) logSD();
      flag=0;
      break;
    default:
      flag=0;
      break;
  }
  //Serial.print("EndLoop");
  
  /* 
  if (flag_last!=flag){
    lcd.clear();
    flag_last=flag;
  }
  
  if (light_last!=light){
    if (light){
      lcd.setBacklight(BACKLIGHT_ON);
    } else {
      lcd.setBacklight(BACKLIGHT_OFF);
    }
  }
  light_last=light;
  */
}

ISR(TIMER1_COMPA_vect)
{
    seconds++;
    if (seconds == 5) //15 for every minute i.e. 60s / 4s per interrupt
    {
        seconds = 0;
        flag=10;
    }
} 


ISR (INT0_vect)
{
  flag++;
  flag=flag % 3;
  //lcd.clear();
    /* interrupt code here */
}

void swap()
{
  flag++;
  flag=flag % 3;
  lcd.clear();
  delay(150);
}

void togglebl()
{
  light=!light;
}

void showTimeScreen()
{
  DateTime now = rtc.now();
  sprintf(data,  "%02d/%02d   %02d:%02d:%02d", now.day(), now.month(), now.hour(), now.minute(), now.second() );
  lcd.setCursor(0, 0);
  lcd.print(data);
  lcd.setCursor(1, 1);
  sensors.requestTemperatures();
  lcd.print(sensors.getTempC(T1),1);
  lcd.print((char)223);
  lcd.print("C  ");
  lcd.print(0.01*mapfloat(analogRead(sensorPin),phL,phH,phLv,phHv),2);
  lcd.print("Ph");
}

void showReadingsScreen()
{
      lcd.setCursor(1, 0);
    sensors.requestTemperatures();
    float tempC = sensors.getTempC(T1);
    
    if (tempC == -127.00) {
      lcd.print("Error Temp");
    } else {
      lcd.print("Temp: ");
      lcd.print(tempC,2);
      lcd.print(" ");
      lcd.print((char)223);
      lcd.print("C");
    }
    lcd.setCursor(1, 1);
    lcd.print("Ph  :  ");
    lcd.print(mapfloat(analogRead(sensorPin),0,1023,0,500)/100,2);
    lcd.print(" V");
    delay(1000);
    
  }
  
void showMenu()
{
  lcd.setCursor(0, 0);
  lcd.print("MENU");
  
}


void logData() {
  
  DateTime now = rtc.now();
  sensors.requestTemperatures();
  float reading = 0.01*mapfloat(analogRead(sensorPin),phL,phH,phLv,phHv);
  Serial.println(reading);
  delay(700);
  dtostrf(reading,1,2,csPh);
  Serial.println(csPh);
  dtostrf(sensors.getTempC(T1),1,2,csT);  
  sprintf(data,  "%d,%d,%d,%d,%d,%d,%s,%s", now.year(), now.month(), now.day(), now.hour(), now.minute(), now.second(), csT, csPh );
  //String dlog = String(dateb) + String(sValb);
  //dlog = dlog + String(sValb);
  //dlog = dlog + ",";  
  //dlog= dlog + String(sValb);
  //return String(dlog); 
}

void logSD() {
  lcd.clear();
  lcd.setCursor(0, 0);  
  // if the file opened okay, write to it:
  lcd.print("SD Writing...");
  logData();
  Serial.println(data);
  sdLog.println(data);  
//  delay(1000);
//  close the file:
//  sdLog.close();
  lcd.clear();
  if (!sdLog.sync()) {
    lcd.print("SD Writing failed");
    sd.errorPrint();
  } else {
    lcd.print("SD Writing done");
  };
  delay(1000);
}

float mapfloat(long x, long in_min, long in_max, int out_min, long out_max)
{
  return (float)(x - in_min) * (out_max - out_min) / (float)(in_max - in_min) + out_min;
}
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

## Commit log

2014-02-16 Initial commit of arduino program - Basic reading and dummy conversion of ph probe, OneWire temperature & DS1307 RTC; display on lcd connected through i2c
2014-02-16 Added missing dummy calibration points
    [AquaCont.ino]
2014-02-17 Preliminary board design (no PCB routing yet)
    [aquaMain.brd, aquaMain.sch, aquaPh.brd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]
2014-02-17 Added calibration function / UI and saving to EEPROM No-delay counting down waiting for button press
2014-03-24 Finished experimental board design Added PCB converted Arduino NANO <-> DIP 28
    [aquaPh.brd, aquaUI.sch, nano_to_DIP.brd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]
2014-03-24 Filled empty spaces with copper (faster eatching) Redone ArduinoNANO to DIP28 PCB to a single-side version Added V1 printout image
    [aquaMain.brd, aquaMain.sch, aquaPh.brd]
2014-05-17 Big update Many important fixes dictated by 1st prototype
    [aquaMain.brd, aquaMain.sch, aquaPh.brd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]
2014-05-20 - important fix to SD wiring (not implemented in PCB yet) - SD logging function in arduino project
    [aquaMain.brd, aquaMain.sch]
2015-01-09 Final project commit: - prototype proven to working continously for 4 months as of 1/8/15 - added pictures - [1/5/15] improvement - decrease R2 to 2.2kOhm, improved SNR from DS18B20 - project finished
    Achieved:
    - LCD display over i2c interface
    - Functional 3-button menu English and Polish
    - Ph probe reading with calibration code
    - EEPROM save of Ph calibration
    - Temperature reading [DS18B20]
    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
    [aquaMain.brd, aquaMain.sch, aquaPh.brd]

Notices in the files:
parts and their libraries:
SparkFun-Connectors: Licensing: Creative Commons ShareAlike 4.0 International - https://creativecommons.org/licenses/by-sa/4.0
